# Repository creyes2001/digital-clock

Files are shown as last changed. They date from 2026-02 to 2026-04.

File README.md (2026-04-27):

# DIGITAL CLOCK

## Overview

This is a bare-metal C project based on the Microchip PIC18F4550 microcontroller that implements a digital clock.
The system uses multiplexed seven-segment displays to show the current time and provides a push-button interface for user configuration.
The configured time is stored in the internal EEPROM memory.

## Features

- Modular driver-based firmware architecture
- Timer2-driven system tick for timekeeping and scheduling
- Multiplexed seven-segment display control
- Push-button interface for user configuration
- EEPROM-based non-volatile time storage

## Hardware 

- Microchip PIC18F4550 microcontroller with a 16 MHz external crystal oscillator 
- Multiplexed common-cathode seven-segment display
- NPN transistors for digit control
- Push-button interface with pull-up resistors

## Software architecture

The firmware is organized using a modular architecture that separates hardware drivers from application logic.

The modules include:

- GPIO HAL for low-level pin control
- Display driver for multiplexed seven-segment control
- Button driver for user input handling
- System tick dirver providing a 1 ms time base
- EEPROM driver for non-volatile data storage
- Clock driver for real-time management
- UART driver for testing and debugging

## How It Works?

The system operates on a 1 ms system tick generated by the Timer2 peripherial.
The tick drives a cooperative scheduler responsible for executing periodic tasks and maintaining the system time.
The scheduler manages key tasks such as button input processing, display multiplexing, and timekeeping.
This approach ensures accurate timing efficient CPU utilization.

## Challenges & Design Decisions

### Display ghosting

My initial design used common-anode displays driven by PNP transistors 
through a Darlington array, chosen to limit the current going through 
the PIC's GPIO pins. This setup caused visible ghosting: the Darlington 
array's slow switching times and high saturation voltage drop meant 
that the previous digit didn't fully turn off before the next one 
turned on during multiplexing.

I redesigned the digit-drive stage with common-cathode displays driven 
directly by NPN transistors. The faster switching produced cleaner 
digit transitions and eliminated the ghosting entirely. This taught me 
that in embedded development, firmware correctness alone isn't enough — 
the underlying circuit topology can make or break a working system.

## Build Instruction
```bash
make all
make flash
make clean
```
## Schematic
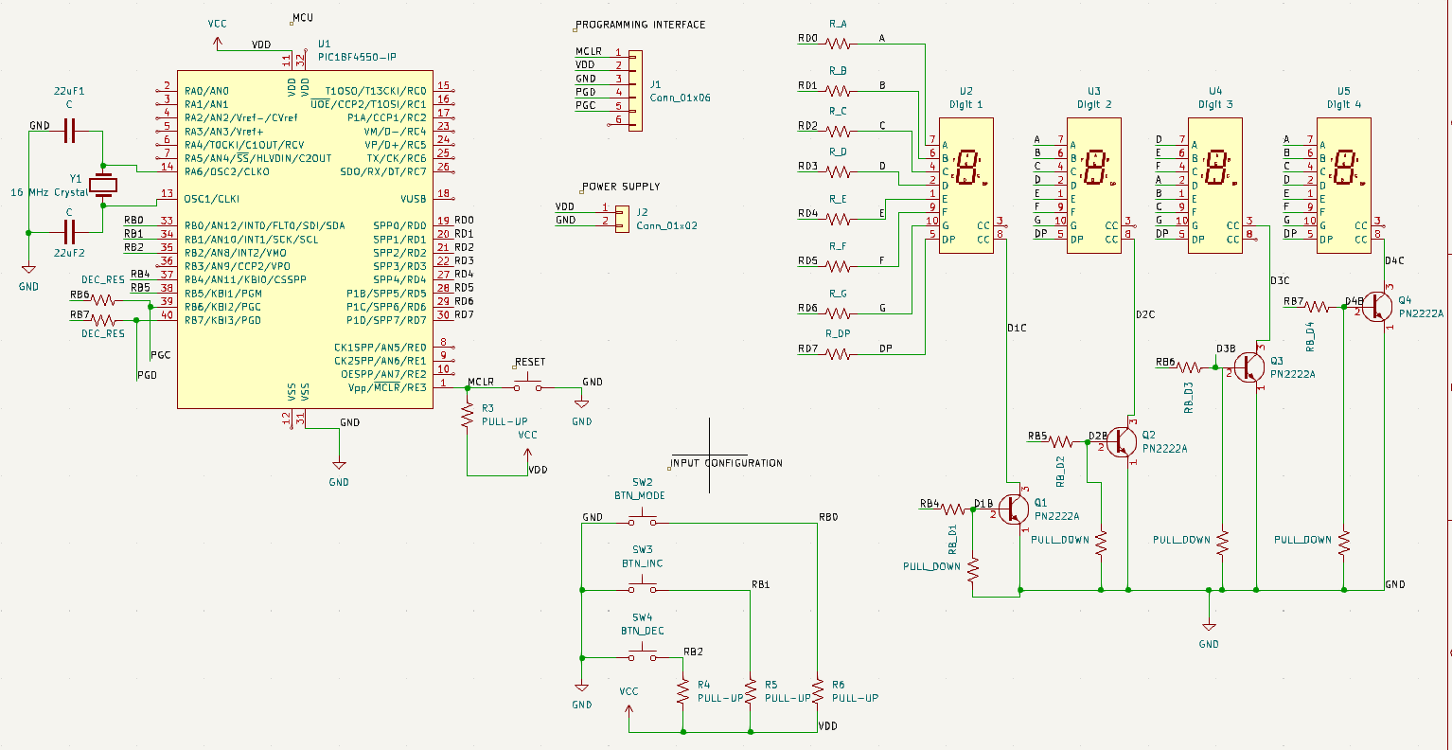
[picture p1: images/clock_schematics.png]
schematic


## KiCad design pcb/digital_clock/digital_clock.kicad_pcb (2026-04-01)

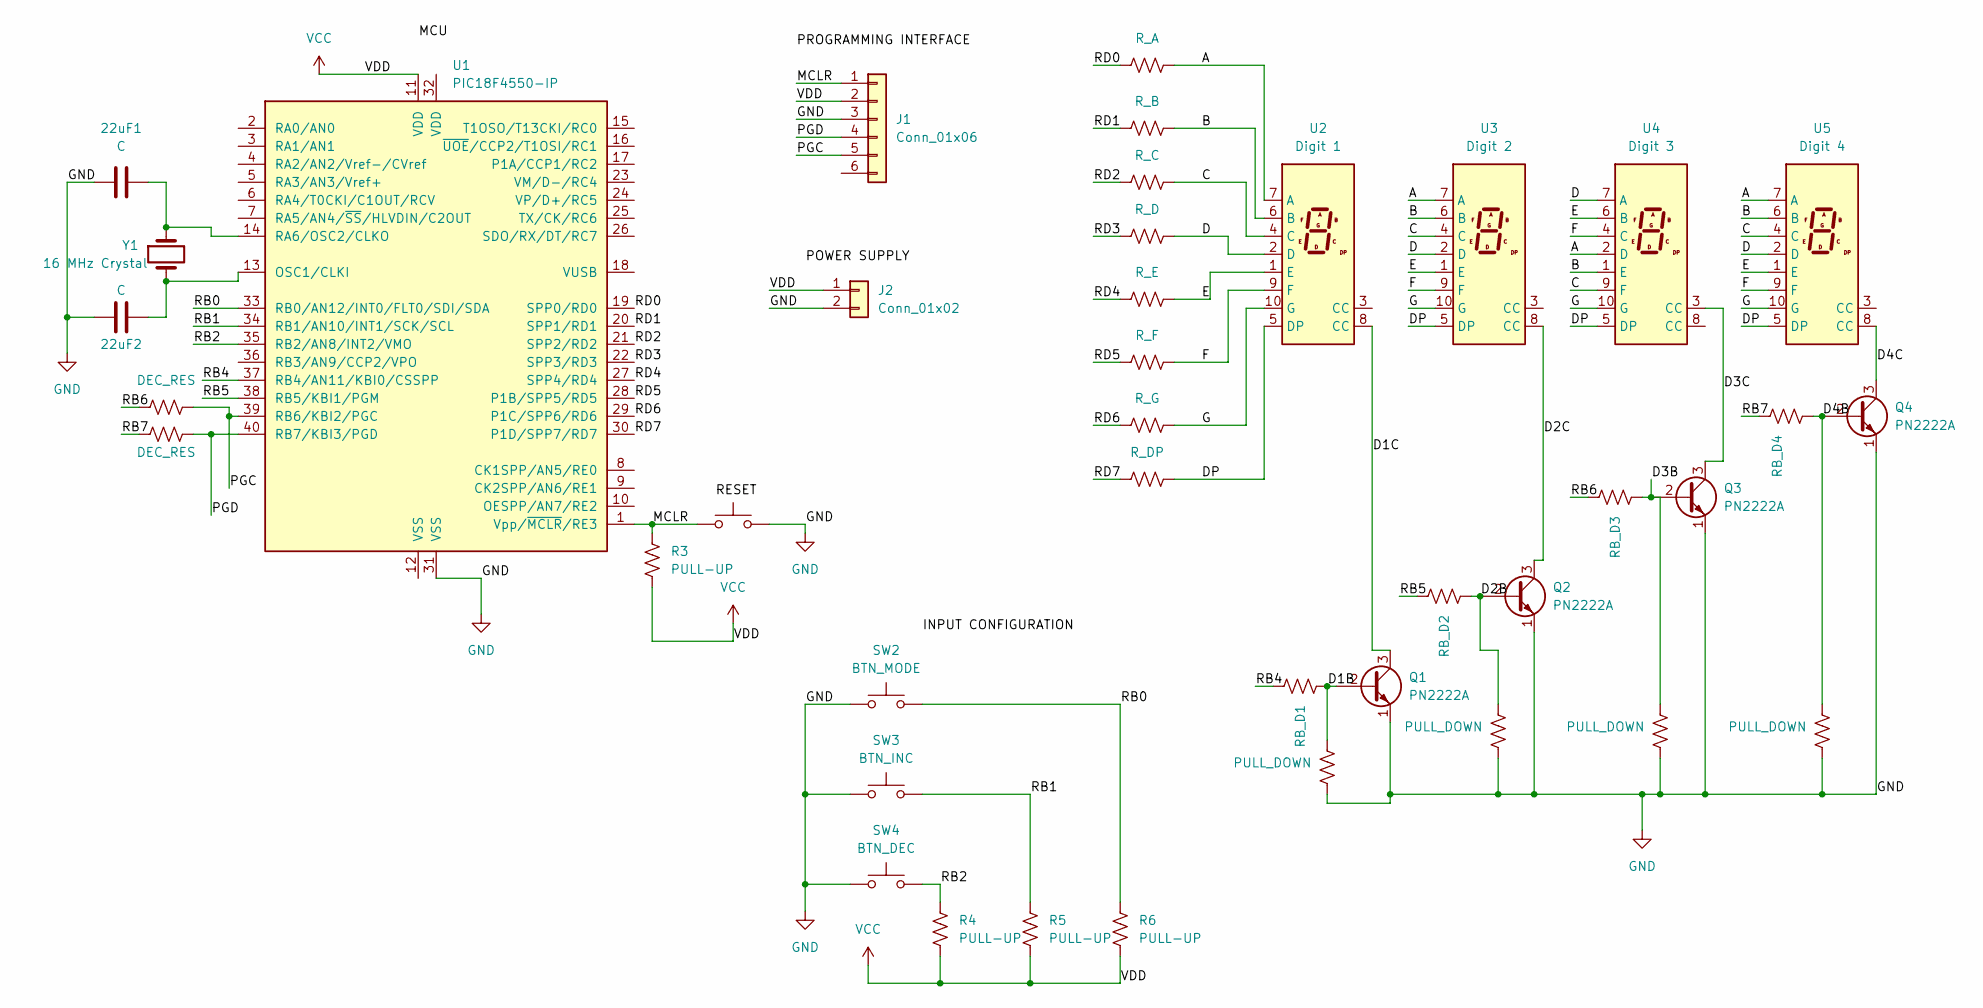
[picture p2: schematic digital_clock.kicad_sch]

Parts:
22uF1, 22uF2: C; C_Disc_D3.0mm_W1.6mm_P2.50mm
J1: Conn_01x06; PinHeader_1x06_P2.54mm_Horizontal
J2: Conn_01x02; PhoenixContact_MCV_1,5_2-G-5.08_1x02_P5.08mm_Vertical
Q1, Q2, Q3, Q4: PN2222A; TO-92_Inline
R1, R2: DEC_RES; R_Axial_DIN0207_L6.3mm_D2.5mm_P7.62mm_Horizontal
R3, R4, R5, R6: PULL-UP; R_Axial_DIN0207_L6.3mm_D2.5mm_P7.62mm_Horizontal
R7: R_A; R_Axial_DIN0207_L6.3mm_D2.5mm_P7.62mm_Horizontal
R8: R_B; R_Axial_DIN0207_L6.3mm_D2.5mm_P7.62mm_Horizontal
R9: R_C; R_Axial_DIN0207_L6.3mm_D2.5mm_P7.62mm_Horizontal
R10: R_D; R_Axial_DIN0207_L6.3mm_D2.5mm_P7.62mm_Horizontal
R11: R_E; R_Axial_DIN0207_L6.3mm_D2.5mm_P7.62mm_Horizontal
R12: R_F; R_Axial_DIN0207_L6.3mm_D2.5mm_P7.62mm_Horizontal
R13: R_G; R_Axial_DIN0207_L6.3mm_D2.5mm_P7.62mm_Horizontal
R14: R_DP; R_Axial_DIN0207_L6.3mm_D2.5mm_P7.62mm_Horizontal
R15: RB_D1; R_Axial_DIN0207_L6.3mm_D2.5mm_P7.62mm_Horizontal
R16, R18, R20, R22: PULL_DOWN; R_Axial_DIN0207_L6.3mm_D2.5mm_P7.62mm_Horizontal
R17: RB_D2; R_Axial_DIN0207_L6.3mm_D2.5mm_P7.62mm_Horizontal
R19: RB_D3; R_Axial_DIN0207_L6.3mm_D2.5mm_P7.62mm_Horizontal
R21: RB_D4; R_Axial_DIN0207_L6.3mm_D2.5mm_P7.62mm_Horizontal
SW1: SW_Push; SW_PUSH_6mm
SW2: BTN_MODE; SW_PUSH_6mm
SW3: BTN_INC; SW_PUSH_6mm
SW4: BTN_DEC; SW_PUSH_6mm
U1: PIC18F4550-IP; DIP-40_W15.24mm
U2: Digit 1; D1X8K
U3: Digit 2; D1X8K
U4: Digit 3; D1X8K
U5: Digit 4; D1X8K
Y1: 16 MHz Crystal; Crystal_HC49-4H_Vertical

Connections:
/A: R7.1, U2.7 (A), U3.7 (A), U4.2 (D), U5.7 (A)
/B: R8.1, U2.6 (B), U3.6 (B), U4.1 (E), U5.6 (B)
/C: R9.1, U2.4 (C), U3.4 (C), U4.9 (F), U5.4 (C)
/D: R10.1, U2.2 (D), U3.2 (D), U4.7 (A), U5.2 (D)
/D1B: Q1.2 (B), R15.1, R16.2
/D1C: Q1.3 (C), U2.8 (CC)
/D2B: Q2.2 (B), R17.1, R18.2
/D2C: Q2.3 (C), U3.8 (CC)
/D3B: Q3.2 (B), R19.1, R20.2
/D3C: Q3.3 (C), U4.3 (CC)
/D4B: Q4.2 (B), R21.1, R22.2
/D4C: Q4.3 (C), U5.8 (CC)
/DP: R14.1, U2.5 (DP), U3.5 (DP), U4.5 (DP), U5.5 (DP)
/E: R11.1, U2.1 (E), U3.1 (E), U4.6 (B), U5.1 (E)
/F: R12.1, U2.9 (F), U3.9 (F), U4.4 (C), U5.9 (F)
/G: R13.1, U2.10 (G), U3.10 (G), U4.10 (G), U5.10 (G)
/MCLR: J1.1, R3.1, SW1.1, U1.1 (Vpp/~MCLR/RE3)
/PGC: J1.5, R1.1, U1.39 (RB6/KBI2/PGC)
/PGD: J1.4, R2.1, U1.40 (RB7/KBI3/PGD)
/RB0: R6.1, SW2.2, U1.33 (RB0/AN12/INT0/FLT0/SDI/SDA)
/RB1: R5.1, SW3.2, U1.34 (RB1/AN10/INT1/SCK/SCL)
/RB2: R4.1, SW4.2, U1.35 (RB2/AN8/INT2/VMO)
/RB4: R15.2, U1.37 (RB4/AN11/KBI0/CSSPP)
/RB5: R17.2, U1.38 (RB5/KBI1/PGM)
/RB6: R1.2, R19.2
/RB7: R2.2, R21.2
/RD0: R7.2, U1.19 (SPP0/RD0)
/RD1: R8.2, U1.20 (SPP1/RD1)
/RD2: R9.2, U1.21 (SPP2/RD2)
/RD3: R10.2, U1.22 (SPP3/RD3)
/RD4: R11.2, U1.27 (SPP4/RD4)
/RD5: R12.2, U1.28 (P1B/SPP5/RD5)
/RD6: R13.2, U1.29 (P1C/SPP6/RD6)
/RD7: R14.2, U1.30 (P1D/SPP7/RD7)
GND: 22uF1.2, 22uF2.2, J1.3, J2.2, Q1.1 (E), Q2.1 (E), Q3.1 (E), Q4.1 (E), R16.1, R18.1, R20.1, R22.1, SW1.2, SW2.1, SW3.1, SW4.1, U1.31 (VSS)
unnamed: 22uF2.1, U1.13 (OSC1/CLKI), Y1.2
unnamed: 22uF1.1, U1.14 (RA6/OSC2/CLKO), Y1.1
VCC: J1.2, J2.1, R3.2, R4.2, R5.2, R6.2, U1.11 (VDD)

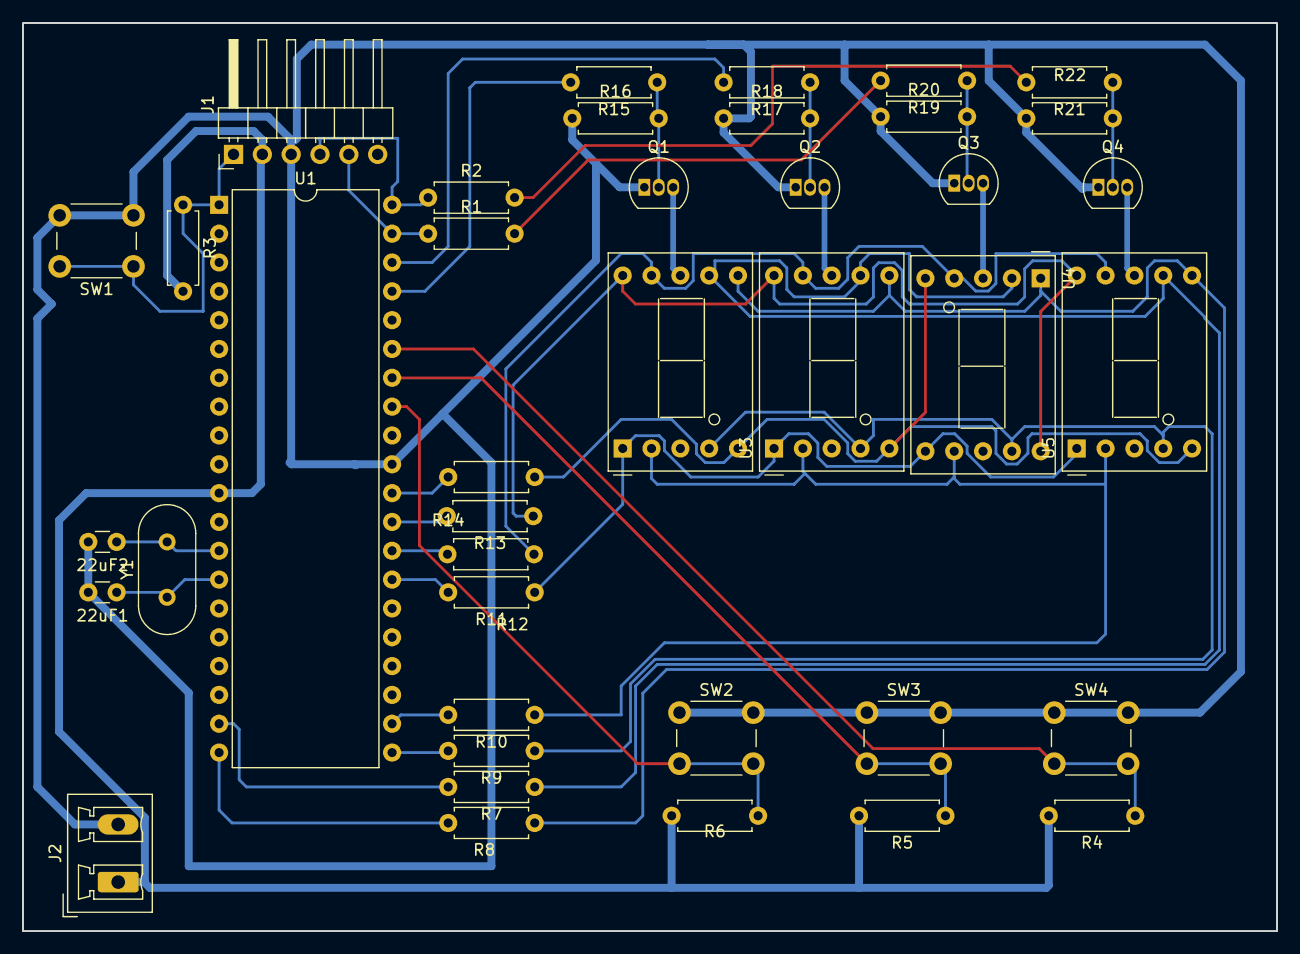
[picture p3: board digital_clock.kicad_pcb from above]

Board: 2 copper layers, 110.5 x 80.0 mm, 40 parts (0 on the bottom side), 38 nets.

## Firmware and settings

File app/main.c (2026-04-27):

#include "app.h"
#include "isr.h"
#include "gpio.h"
#include "config.h"
#include "printf.h"
#include "timer2.h"
#include "system_tick.h"
#include "clock.h"
#include "ss_display.h"
#include "uart.h"
#include <xc.h>

//-----------DISPLAY CONFIG---------------
gpio_t data[7] = {
	{
		.tris = &TRISD,
		.lat = &LATD,
		.port = &PORTD,
		.pin = 0
	},

	{
		.tris = &TRISD,
		.lat = &LATD,
		.port = &PORTD,
		.pin = 1
	},

	{
		.tris = &TRISD,
		.lat = &LATD,
		.port = &PORTD,
		.pin = 2
	},
	
	{
		.tris = &TRISD,
		.lat = &LATD,
		.port = &PORTD,
		.pin = 3
	},
	
	{
		.tris = &TRISD,
		.lat = &LATD,
		.port = &PORTD,
		.pin = 4
	},
	
	{
		.tris = &TRISD,
		.lat = &LATD,
		.port = &PORTD,
		.pin = 5
	},
	
	{
		.tris = &TRISD,
		.lat = &LATD,
		.port = &PORTD,
		.pin = 6
	}
};
	
gpio_t control[4] = {
	{
		.tris = &TRISB,
		.lat = &LATB,
		.port = &PORTB,
		.pin = 4
	},

	{
		.tris = &TRISB,
		.lat = &LATB,
		.port = &PORTB,
		.pin = 5
	},

	{
		.tris = &TRISB,
		.lat = &LATB,
		.port = &PORTB,
		.pin = 6
	},

	{
		.tris = &TRISB,
		.lat = &LATB,
		.port = &PORTB,
		.pin = 7
	}
};

gpio_t colon = {
	.tris = &TRISD,
	.lat = &LATD,
	.port = &PORTD,
	.pin = 7
};

gpio_t colon_control = {
	.tris = &TRISE,
	.lat = &LATE,
	.port = &PORTE,
	.pin = 0
};
	

display_t clk_display = {
	.colon = COLON_ENABLED,
	.segment_polarity = ACTIVE_HIGH,
	.control_polarity = ACTIVE_HIGH,
	.digit_number = 4,
	.data = data,
	.control = control, 
	.colon_pin = &colon,
	.colon_control_pin = &colon_control
};
//----------------------------------------

//-----------UART CONFIG------------------
static gpio_t rx = {
	.tris = &TRISC,
	.lat = &LATC,
	.port = &PORTC,
	.pin = 7
};

static gpio_t tx = {
	.tris = &TRISC,
	.lat = &LATC,
	.port = &PORTC,
	.pin = 6
};

uart_config_t uart_config = {
	.rx = &rx,
	.tx = &tx,
	.baud_rate = 9600
};
//---------------------------------------

clock_time_t sys_clock;
app_t app;

/* debug configuration*/
gpio_t debug_pin = {
	.tris = &TRISC,
	.port = &PORTC,
	.lat = &LATC,
	.pin = 0
};

void clock_1hz_debug(gpio_t *debug_p)
{
	static volatile uint16_t ms = 0;

	ms++;
	if(ms>=1)
	{
		ms = 0;
		Gpio_Toggle(debug_p);
	}
}

int main()
{

	App_Init(&app,&sys_clock);

	//Uart_Init(&uart_config);
	//Uart_Start(&uart_config);

	timer2_init();
	timer2_start();

	display_init(&clk_display);

	/* Enable interrupts */
	isr_init();

	/* CLock initialization */	
	uint8_t hours = 0, minutes = 0, seconds = 0;
	clock_init(&sys_clock,hours,minutes,seconds);

	Gpio_Init(&debug_pin,GPIO_OUTPUT);
	while(1)
	{
		system_tick_task();
		App_Task(&app);

		if(system_tick_is_1ms())
		{
			Button_Task();
			display_task();
	 	//	clock_1hz_debug(&debug_pin);
		}

		if(system_tick_is_1s())
		{
			clock_update_1s(&sys_clock);
			if(app.state == APP_STATE_RUN)
			{
				display_push(get_time(&sys_clock));
				display_set_colon_blink(500);
			}
		}
		
		if(app.state == APP_STATE_SET_HOURS)
		{
			display_set_colon_blink(150);
			display_push(get_time(&sys_clock));
		}

		if(app.state == APP_STATE_SET_MINUTES)
		{
			display_set_colon_blink(150);
			display_push(get_time(&sys_clock));
		}
	}
	return 0;
}

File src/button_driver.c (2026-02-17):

#include "button_driver.h"

void button_init(button_t *btn, gpio_t *gpio,button_polarity_e polarity,uint8_t debounce_ticks)
{
	btn->gpio = gpio;
	btn->polarity = polarity;
	btn->state = BUTTON_RELEASED;
	btn->last_state = BUTTON_RELEASED;
	btn->debounce_cnt = 0;
	btn->debounce_ticks = debounce_ticks;
	btn->event = BUTTON_EVENT_NONE;

	Gpio_Init(btn->gpio,GPIO_INPUT);
}

void button_update(button_t *btn)
{
	button_state_e state;
	if(btn->polarity == BUTTON_ACTIVE_HIGH)
	{
		state = (Gpio_Read(btn->gpio)== GPIO_HIGH) ? BUTTON_PRESSED : BUTTON_RELEASED;	
	}
	else
	{
		state = (Gpio_Read(btn->gpio)== GPIO_HIGH) ? BUTTON_RELEASED : BUTTON_PRESSED; 	
	}
	
	if(state == btn->state)
	{
		btn->debounce_cnt = 0;
	}
	else{
		btn->debounce_cnt++;
		if(btn->debounce_cnt >= btn->debounce_ticks)
		{
			btn->last_state = btn->state;
			btn->state = state;

			if(btn->last_state == BUTTON_RELEASED  && btn->state == BUTTON_PRESSED)
			{
				btn->event = BUTTON_EVENT_PRESSED;
			}
			else if(btn->last_state == BUTTON_PRESSED && btn->state == BUTTON_RELEASED)
			{
				btn->event = BUTTON_EVENT_RELEASED;
			}
			btn->debounce_cnt = 0;
		}
	}
}

button_event_e button_get_event(button_t *btn)
{
	button_event_e event = btn->event;
	btn->event = BUTTON_EVENT_NONE;
	return event;
}

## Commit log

2026-01-29 Add gpio driver skeleton
2026-01-31 Add UART driver skeleton
2026-01-31 Add Uart driver improvements and logic
2026-01-31 Fix: Define gpio structs pinters inside the uart structure
    [main.c, uart.c]
2026-02-05 feat: implemented TXIF polling for UART transmission
2026-02-12 Implement UART transmission and reception using ring buffers
2026-02-13 Implement interrupt-driven reception
2026-02-14 Implemented Uart interrupt-driven transmission
2026-02-16 Add external printf implementation for embedded systems
2026-02-16 Included and tested the external printf implementation
2026-02-16 Include timer 0 driver files from past projects
2026-02-17 Add interrupt module to centralize ISR dispatching and global interrupt initialization
2026-02-17 feat: integrate debounced button driver with system tick
2026-03-11 feat: Add colon blink function inside the display driver
2026-03-13 Fix: reduce ghosting during display multiplexing
    [main.c, ss_display.c]
2026-03-24 fix: improve system time base accuracy with Timer 2 driver
    [main.c, ss_display.c]
2026-04-01 Docs: add schematic image
    [digital_clock-B_Cu.gbr, digital_clock-B_Mask.gbr, digital_clock-B_Paste.gbr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]
2026-04-01 Fix: schematic image path
